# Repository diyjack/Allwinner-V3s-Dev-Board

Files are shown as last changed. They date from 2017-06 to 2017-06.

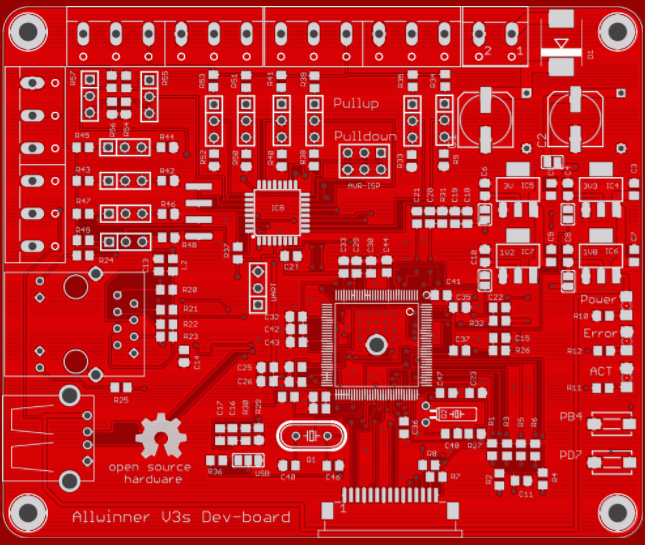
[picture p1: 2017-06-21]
Hardware/Bilder-Platine/top.png

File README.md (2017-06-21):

# Allwinner-V3s-Dev-Board
Entwicklungsplatine für den nicht sehr bekannten V3s Soc von Allwinner. <br>In dieser Version wurde speziell auf die Multimedia Interfaces des V3s verzichtet um das Entwicklungsboard so einfach wie möglich zu halten.<br> Das Entwicklungsboard verfügt über eine 100mbit Ethernet Buchse,
einen USB Host, ein MIPI Kamera Interface(welches kompatibel zur Raspberry Pi Kamera ist), desweiteren kann über eine micro SD-Karte gebootet werden.<br>
Das Entwicklungsboard verfügt über 12 Eingänge / Ausgänge die auf einer Wago-Klemme aufgelegt sind.<br>Das Entwicklungsboard kann mit bis zu 35V DC betrieben werden.<br> Dieses Entwicklungsboard wurde für die Verwendung im industriellen Bereich entwickelt.
Der CO-Prozessor (ATmega328) überwacht die Eingänge und kann ggf. auch geringe Lasten schalten. 

Die Gerber Dateien und der Schaltplan wurden unter der Open Source Hardware Lizenz veröffentlicht und dürfen für den nicht kommerziellen Zweck gerne weiter verwendet werden.

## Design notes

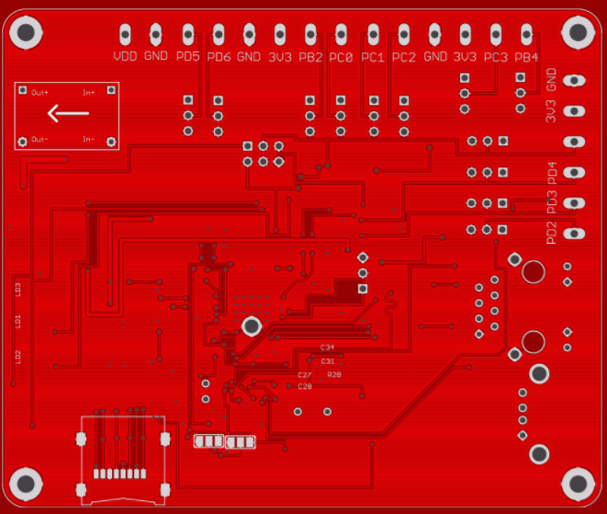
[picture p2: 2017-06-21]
Hardware/Bilder-Platine/Bottom.png

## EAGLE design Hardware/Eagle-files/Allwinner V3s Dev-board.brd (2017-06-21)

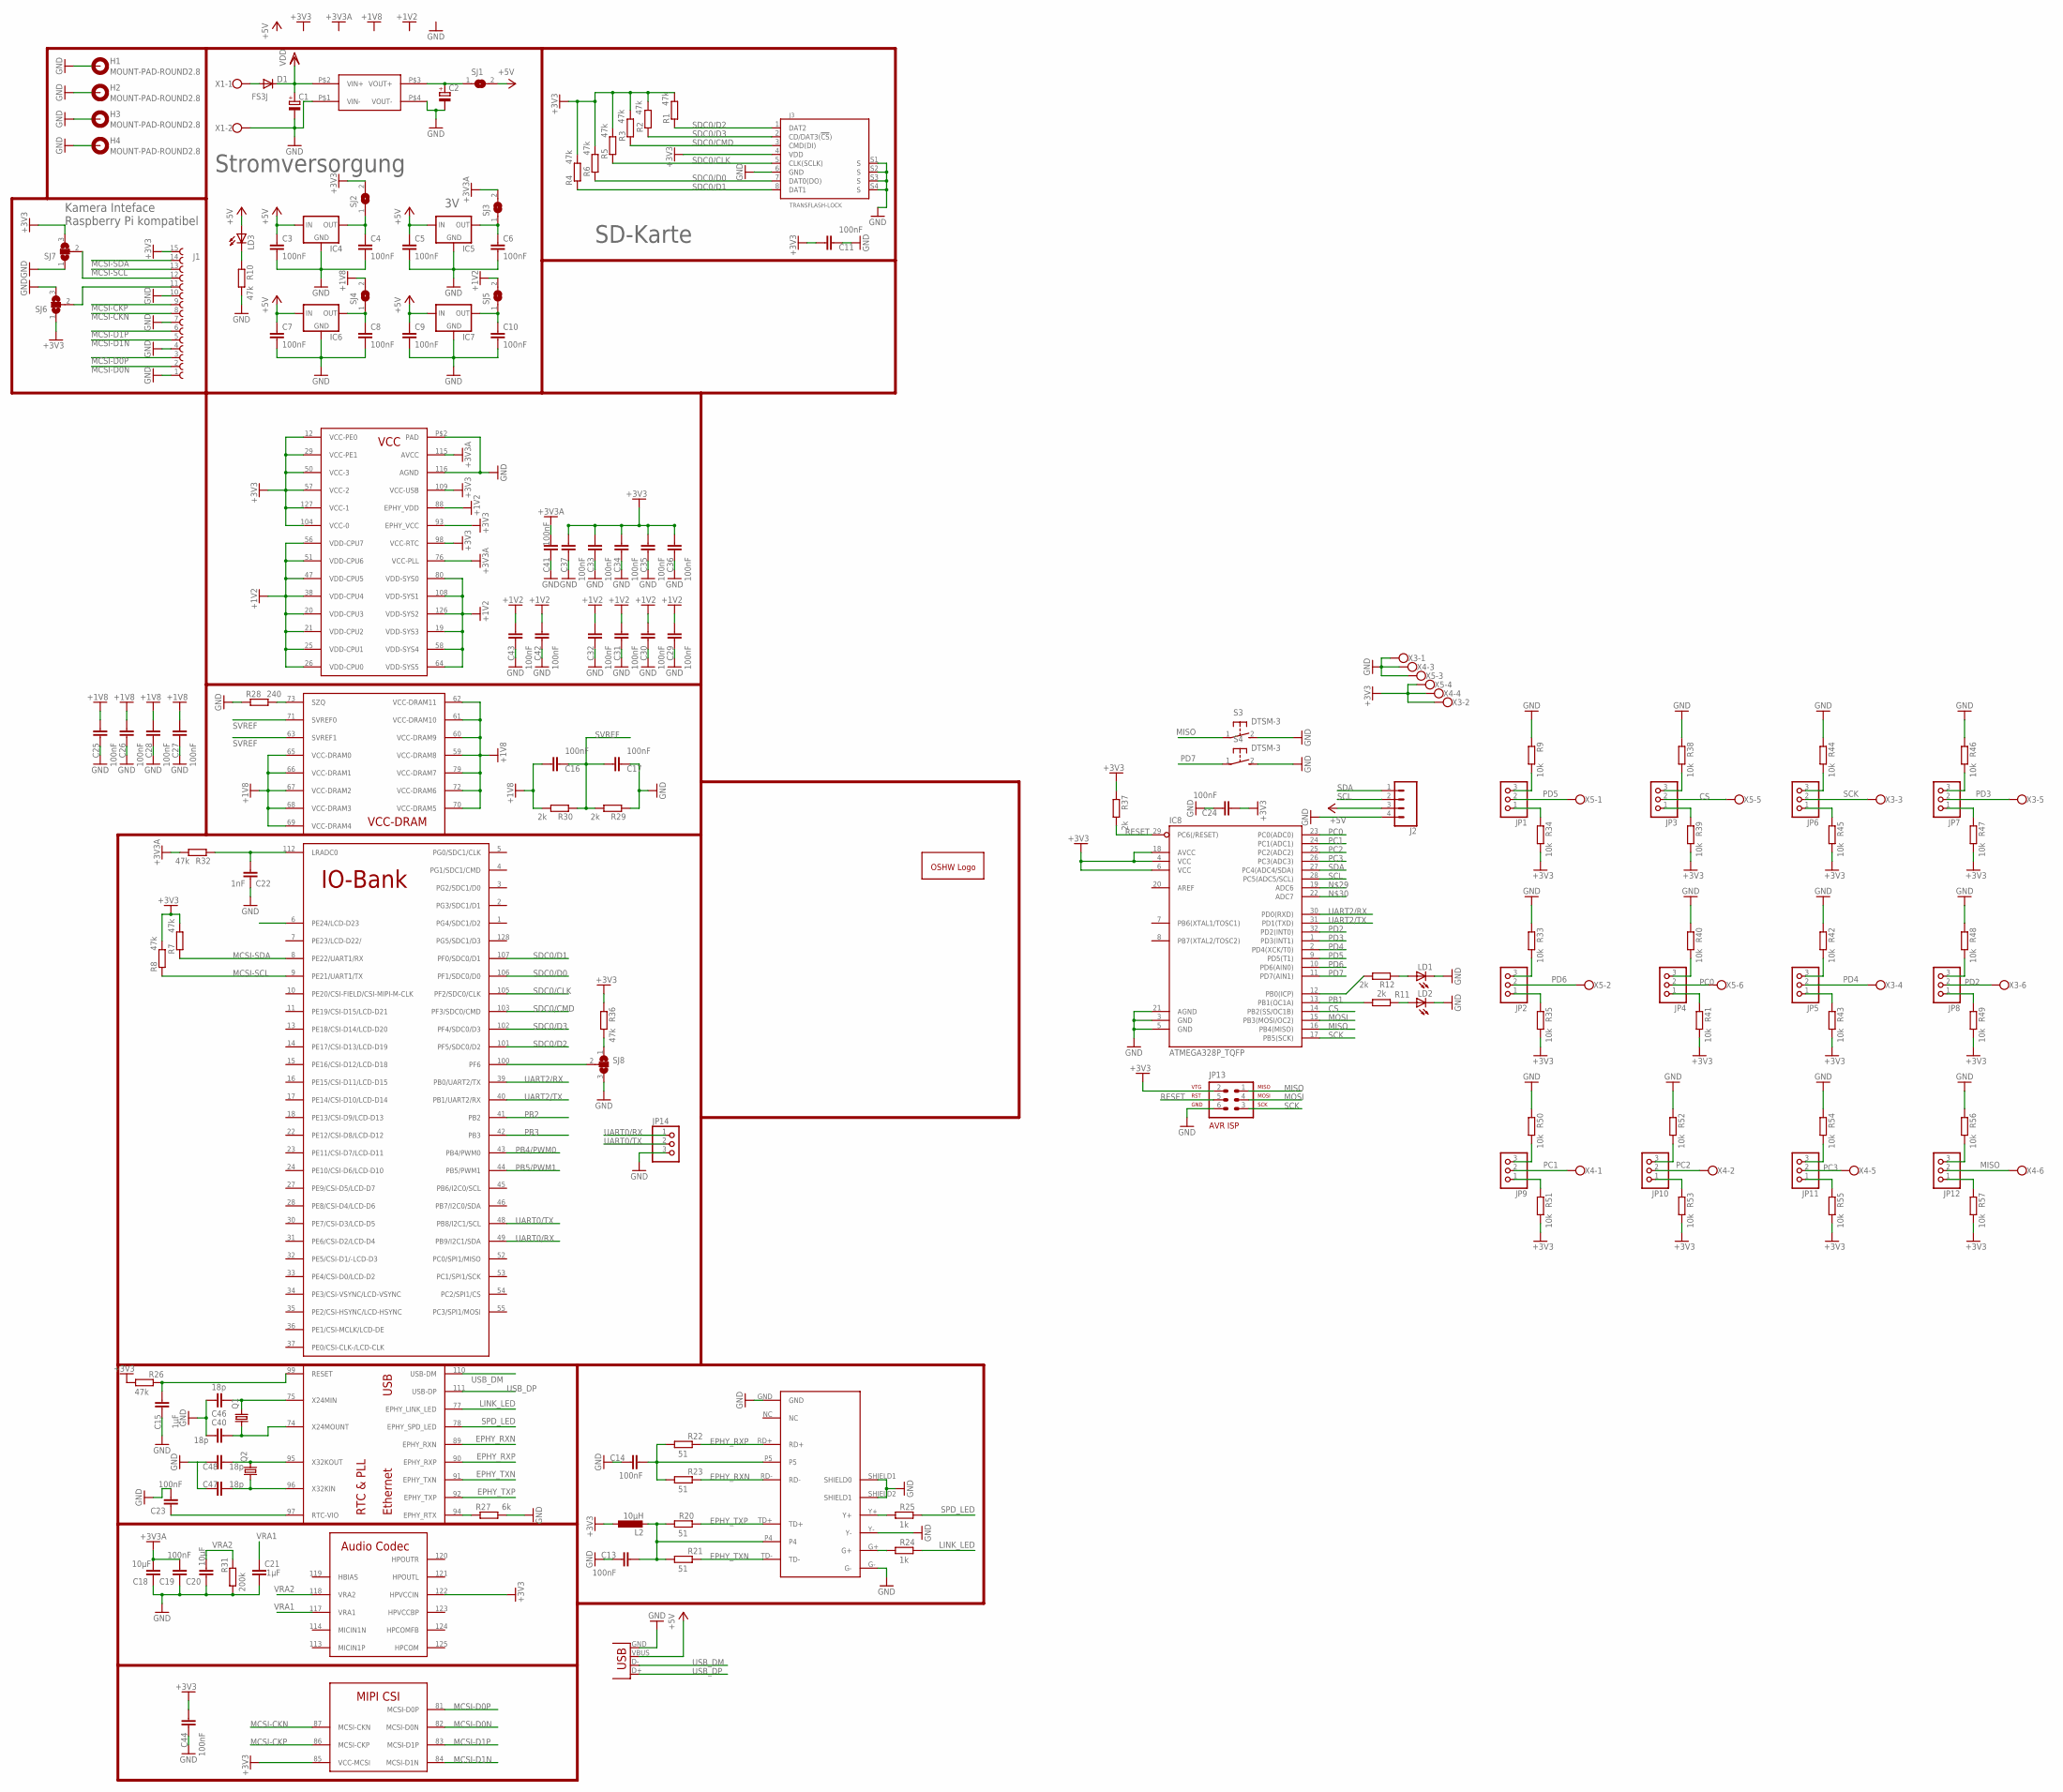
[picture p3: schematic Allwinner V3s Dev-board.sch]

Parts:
C1, C2: CPOL-EU153CLV-0807; 153CLV-0807
C3, C4, C5, C6, C7, C8, C9, C10, C11, C13, C14, C16, C17, C19, C23, C24, C25, C26, C27, C28, C29, C30, C31, C32, C33, C34, C35, C36, C37, C41, C42, C43, C44: 100nF; C0805
C15, C21: 1µF; C0805
C18, C20: 10µF; C0805
C22: 1nF; C0805
C40, C46, C47, C48: 18p; C0805
D1: FS3J; SMC
GOLD_ORB_SM2: OSHWLOGOLOGO8MM; OSHW_8MM
H1, H2, H3, H4: MOUNT-PAD-ROUND2.8; 2,8-PAD
IC1: V3S; QFP-128
IC4, IC5, IC6, IC7: LM1117; SOT223
IC8: ATMEGA328P_TQFP; TQFP32-08
J1: 68611514122
J2: CONN_04SMD_LONG; 1X04_SMD_LONG
J3: TRANSFLASH-LOCK; TRANSFLASH-LOCK-SOCK
JP1, JP2, JP3, JP4, JP5, JP6, JP7, JP8, JP9, JP10, JP11, JP12, JP14: PINHD-1X3; 1X03
JP13: AVR-ISP-6
L2: 10µH; L0805
LD1, LD2, LD3: LEDSMT1206; 1206
M1: MP1584-MINI; MINI-DC-BRICK
Q1: CRYSTALHC49S; HC49/S
Q2: CRYSTALTC26H; TC26H
R1, R2, R3, R4, R5, R6, R7, R8, R10, R26, R32, R36: 47k; R0805
R9, R33, R34, R35, R38, R39, R40, R41, R42, R43, R44, R45, R46, R47, R48, R49, R50, R51, R52, R53, R54, R55, R56, R57: 10k; R0805
R11, R12, R29, R30, R37: 2k; R0805
R20, R21, R22, R23: 51; R0805
R24, R25: 1k; R0805
R27: 6k; R0805
R28: 240; R0805
R31: 200k; R0805
S3, S4: DTSM-3
SJ1, SJ2, SJ3, SJ4, SJ5: SJ
SJ6, SJ7, SJ8: SJ2W; SJ_2
U$3: HR911105A; RJ45
X1: W237-102
X2: USB-A-H
X3, X4, X5: W237-6

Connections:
+1V2: C29.1, C30.1, C31.1, C32.1, C42.1, C43.1, IC1.19 (VDD-SYS3), IC1.20 (VDD-CPU3), IC1.21 (VDD-CPU2), IC1.25 (VDD-CPU1), IC1.26 (VDD-CPU0), IC1.38 (VDD-CPU4), IC1.47 (VDD-CPU5), IC1.51 (VDD-CPU6), IC1.56 (VDD-CPU7), IC1.58 (VDD-SYS4), IC1.64 (VDD-SYS5), IC1.80 (VDD-SYS0), IC1.88 (EPHY_VDD), IC1.108 (VDD-SYS1), IC1.126 (VDD-SYS2), SJ5.2
+1V8: C16.1, C25.1, C26.1, C27.1, C28.1, IC1.59 (VCC-DRAM8), IC1.60 (VCC-DRAM9), IC1.61 (VCC-DRAM10), IC1.62 (VCC-DRAM11), IC1.65 (VCC-DRAM0), IC1.66 (VCC-DRAM1), IC1.67 (VCC-DRAM2), IC1.68 (VCC-DRAM3), IC1.69 (VCC-DRAM4), IC1.70 (VCC-DRAM5), IC1.72 (VCC-DRAM6), IC1.79 (VCC-DRAM7), R30.2, SJ4.2
+3V3: C11.1, C24.1, C33.1, C34.1, C35.1, C36.1, C37.1, C44.1, IC1.12 (VCC-PE0), IC1.29 (VCC-PE1), IC1.50 (VCC-3), IC1.57 (VCC-2), IC1.85 (VCC-MCSI), IC1.93 (EPHY_VCC), IC1.98 (VCC-RTC), IC1.104 (VCC-0), IC1.109 (VCC-USB), IC1.122 (HPVCCIN), IC1.127 (VCC-1), IC8.4 (VCC), IC8.6 (VCC), IC8.18 (AVCC), J1.15 (1), J3.4 (VDD), JP13.2, L2.1, R1.2, R2.2, R3.2, R4.2, R5.2, R6.2, R7.2, R8.2, R26.2, R34.2, R35.2, R36.1, R37.1, R39.2, R41.2, R43.2, R45.2, R47.2, R49.2, R51.2, R53.2, R55.2, R57.2, SJ2.2, SJ6.1, SJ7.3, X3.2, X4.4, X5.4
+3V3A: C18.1, C19.1, C41.1, IC1.76 (VCC-PLL), IC1.115 (AVCC), R32.2, SJ3.2
+5V: C3.1, C5.1, C7.1, C9.1, IC4.3 (IN), IC5.3 (IN), IC6.3 (IN), IC7.3 (IN), J2.3, LD3.A, SJ1.2, X2.VBUS
CS: IC8.14 (PB2(SS/OC1B)), JP3.2, X5.5
EPHY_RXN: IC1.89 (EPHY_RXN), R23.1, U$3.RD-
EPHY_RXP: IC1.90 (EPHY_RXP), R22.1, U$3.RD+
EPHY_TXN: IC1.91 (EPHY_TXN), R21.1, U$3.TD-
EPHY_TXP: IC1.92 (EPHY_TXP), R20.1, U$3.TD+
GND: C1.-, C2.-, C3.2, C4.2, C5.2, C6.2, C7.2, C8.2, C9.2, C10.2, C11.2, C13.2, C14.2, C15.2, C17.2, C18.2, C19.2, C20.2, C21.2, C22.1, C23.1, C24.2, C25.2, C26.2, C27.2, C28.2, C29.2, C30.2, C31.2, C32.2, C33.2, C34.2, C35.2, C36.2, C37.2, C40.1, C41.2, C42.2, C43.2, C44.2, C46.1, C47.1, C48.1, H1.B2,8, H2.B2,8, H3.B2,8, H4.B2,8, IC1.116 (AGND), IC1.P$2 (PAD), IC4.1 (GND), IC5.1 (GND), IC6.1 (GND), IC7.1 (GND), IC8.3 (GND), IC8.5 (GND), IC8.21 (AGND), J1.1 (15), J1.4 (12), J1.7 (9), J1.10 (6), J2.4, J3.6 (GND), J3.S1 (S), J3.S2 (S), J3.S3 (S), J3.S4 (S), JP13.6, JP14.3, LD1.C, LD2.C, M1.P$1 (VIN-), M1.P$4 (VOUT-), R9.1, R10.2, R27.2, R28.1, R29.1, R31.2, R33.1, R38.1, R40.1, R42.1, R44.1, R46.1, R48.1, R50.1, R52.1, R54.1, R56.1, S3.2, S4.2, SJ6.3, SJ7.1, SJ8.3, U$3.G-, U$3.GND, U$3.SHIELD1 (SHIELD0), U$3.SHIELD2 (SHIELD1), U$3.Y-, X1.2, X2.GND, X3.1, X4.3, X5.3
LINK_LED: IC1.77 (EPHY_LINK_LED), R24.1
MCSI-CKN: IC1.87 (MCSI-CKN), J1.8
MCSI-CKP: IC1.86 (MCSI-CKP), J1.9 (7)
MCSI-D0N: IC1.82 (MCSI-D0N), J1.2 (14)
MCSI-D0P: IC1.81 (MCSI-D0P), J1.3 (13)
MCSI-D1N: IC1.84 (MCSI-D1N), J1.5 (11)
MCSI-D1P: IC1.83 (MCSI-D1P), J1.6 (10)
MCSI-SCL: IC1.9 (PE21/UART1/TX), J1.13 (3), R8.1
MCSI-SDA: IC1.8 (PE22/UART1/RX), J1.14 (2), R7.1
MISO: IC8.16 (PB4(MISO)), JP12.2, JP13.1, S3.1, X4.6
MOSI: IC8.15 (PB3(MOSI/OC2)), JP13.4
unnamed: D1.A, X1.1
unnamed: JP2.3, R33.2
unnamed: JP1.3, R9.2
unnamed: C15.1, IC1.99 (RESET), R26.1
unnamed: LD1.A, R12.1
unnamed: LD3.C, R10.1
unnamed: JP1.1, R34.1
unnamed: J1.11 (5), SJ6.2
unnamed: J1.12 (4), SJ7.2
unnamed: IC8.12 (PB0(ICP)), R12.2
unnamed: JP2.1, R35.1
unnamed: JP3.3, R38.2
unnamed: JP3.1, R39.1
unnamed: JP4.3, R40.2
unnamed: C2.+, M1.P$3 (VOUT+), SJ1.1
unnamed: JP4.1, R41.1
unnamed: IC1.94 (EPHY_RTX), R27.1
unnamed: R24.2, U$3.G+
unnamed: IC1.73 (SZQ), R28.2
unnamed: R25.2, U$3.Y+
unnamed: C13.1, L2.2, R20.2, R21.2, U$3.P4
unnamed: C14.1, R22.2, R23.2, U$3.P5
unnamed: C22.2, IC1.112 (LRADC0), R32.1
unnamed: C23.2, IC1.97 (RTC-VIO)
unnamed: IC1.100 (PF6), SJ8.2
unnamed: R36.2, SJ8.1
unnamed: JP5.3, R42.2
unnamed: JP5.1, R43.1
unnamed: JP6.3, R44.2
unnamed: JP6.1, R45.1
unnamed: JP7.3, R46.2
unnamed: JP7.1, R47.1
unnamed: JP8.3, R48.2
unnamed: JP8.1, R49.1
unnamed: JP9.3, R50.2
unnamed: JP9.1, R51.1
unnamed: JP10.3, R52.2
unnamed: JP10.1, R53.1
unnamed: C4.1, IC4.2 (OUT), SJ2.1
unnamed: C6.1, IC5.2 (OUT), SJ3.1
unnamed: C8.1, IC6.2 (OUT), SJ4.1
unnamed: C10.1, IC7.2 (OUT), SJ5.1
unnamed: C40.2, IC1.74 (X24MOUNT), Q1.1
unnamed: C46.2, IC1.75 (X24MIN), Q1.2
unnamed: C47.2, IC1.96 (X32KIN), Q2.1
unnamed: C48.2, IC1.95 (X32KOUT), Q2.2
unnamed: JP11.3, R54.2
unnamed: JP11.1, R55.1
unnamed: JP12.3, R56.2
unnamed: JP12.1, R57.1
unnamed: LD2.A, R11.1
PB1: IC8.13 (PB1(OC1A)), R11.2
PB2: IC1.41 (PB2)
PB3: IC1.42 (PB3)
PB4/PWM0: IC1.43 (PB4/PWM0)
PB5/PWM1: IC1.44 (PB5/PWM1)
PC0: IC8.23 (PC0(ADC0)), JP4.2, X5.6
PC1: IC8.24 (PC1(ADC1)), JP9.2, X4.1
PC2: IC8.25 (PC2(ADC2)), JP10.2, X4.2
PC3: IC8.26 (PC3(ADC3)), JP11.2, X4.5
PD2: IC8.32 (PD2(INT0)), JP8.2, X3.6
PD3: IC8.1 (PD3(INT1)), JP7.2, X3.5
PD4: IC8.2 (PD4(XCK/T0)), JP5.2, X3.4
PD5: IC8.9 (PD5(T1)), JP1.2, X5.1
PD6: IC8.10 (PD6(AIN0)), JP2.2, X5.2
PD7: IC8.11 (PD7(AIN1)), S4.1
RESET: IC8.29 (PC6(/RESET)), JP13.5, R37.2
SCK: IC8.17 (PB5(SCK)), JP6.2, JP13.3, X3.3
SCL: IC8.28 (PC5(ADC5/SCL)), J2.2
SDA: IC8.27 (PC4(ADC4/SDA)), J2.1
SDC0/CLK: IC1.105 (PF2/SDC0/CLK), J3.5 (CLK(SCLK)), R5.1
SDC0/CMD: IC1.103 (PF3/SDC0/CMD), J3.3 (CMD(DI)), R3.1
SDC0/D0: IC1.106 (PF1/SDC0/D0), J3.7 (DAT0(DO)), R6.1
SDC0/D1: IC1.107 (PF0/SDC0/D1), J3.8 (DAT1), R4.1
SDC0/D2: IC1.101 (PF5/SDC0/D2), J3.1 (DAT2), R1.1
SDC0/D3: IC1.102 (PF4/SDC0/D3), J3.2 (CD/DAT3(!CS!)), R2.1
SPD_LED: IC1.78 (EPHY_SPD_LED), R25.1
SVREF: C16.2, C17.1, IC1.63 (SVREF1), IC1.71 (SVREF0), R29.2, R30.1
UART0/RX: IC1.49 (PB9/I2C1/SDA), JP14.1
UART0/TX: IC1.48 (PB8/I2C1/SCL), JP14.2
UART2/RX: IC1.39 (PB0/UART2/TX), IC8.30 (PD0(RXD))
UART2/TX: IC1.40 (PB1/UART2/RX), IC8.31 (PD1(TXD))
USB_DM: IC1.110 (USB-DM), X2.D-
USB_DP: IC1.111 (USB-DP), X2.D+
VDD: C1.+, D1.C, M1.P$2 (VIN+)
VRA1: C21.1, IC1.117 (VRA1)
VRA2: C20.1, IC1.118 (VRA2), R31.1

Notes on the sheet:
Stromversorgung
Kamera Inteface Raspberry Pi kompatibel
SD-Karte

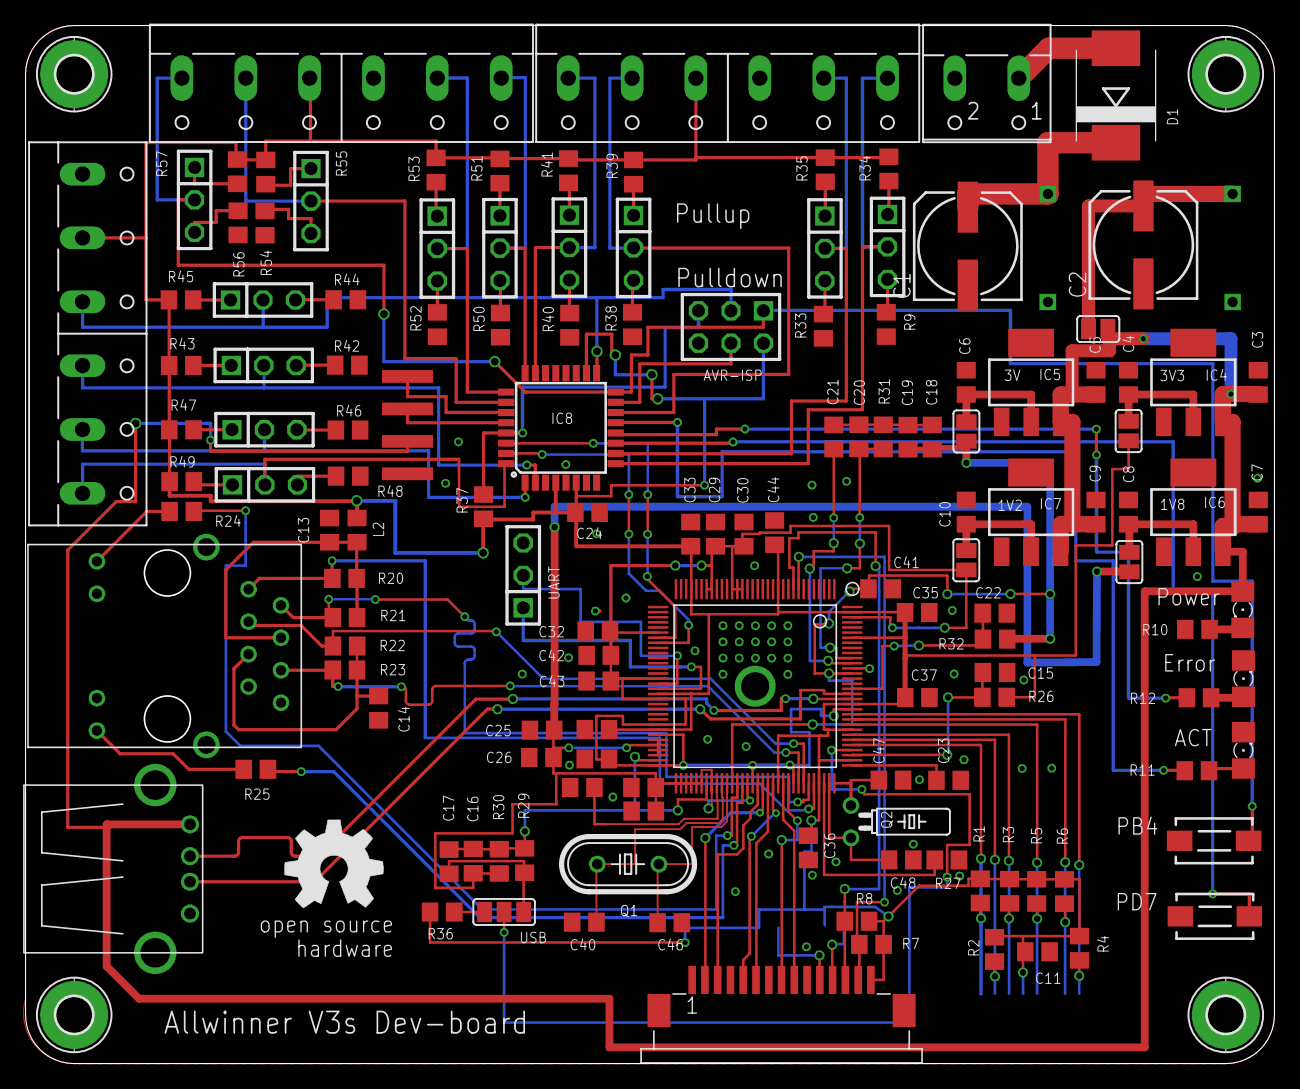
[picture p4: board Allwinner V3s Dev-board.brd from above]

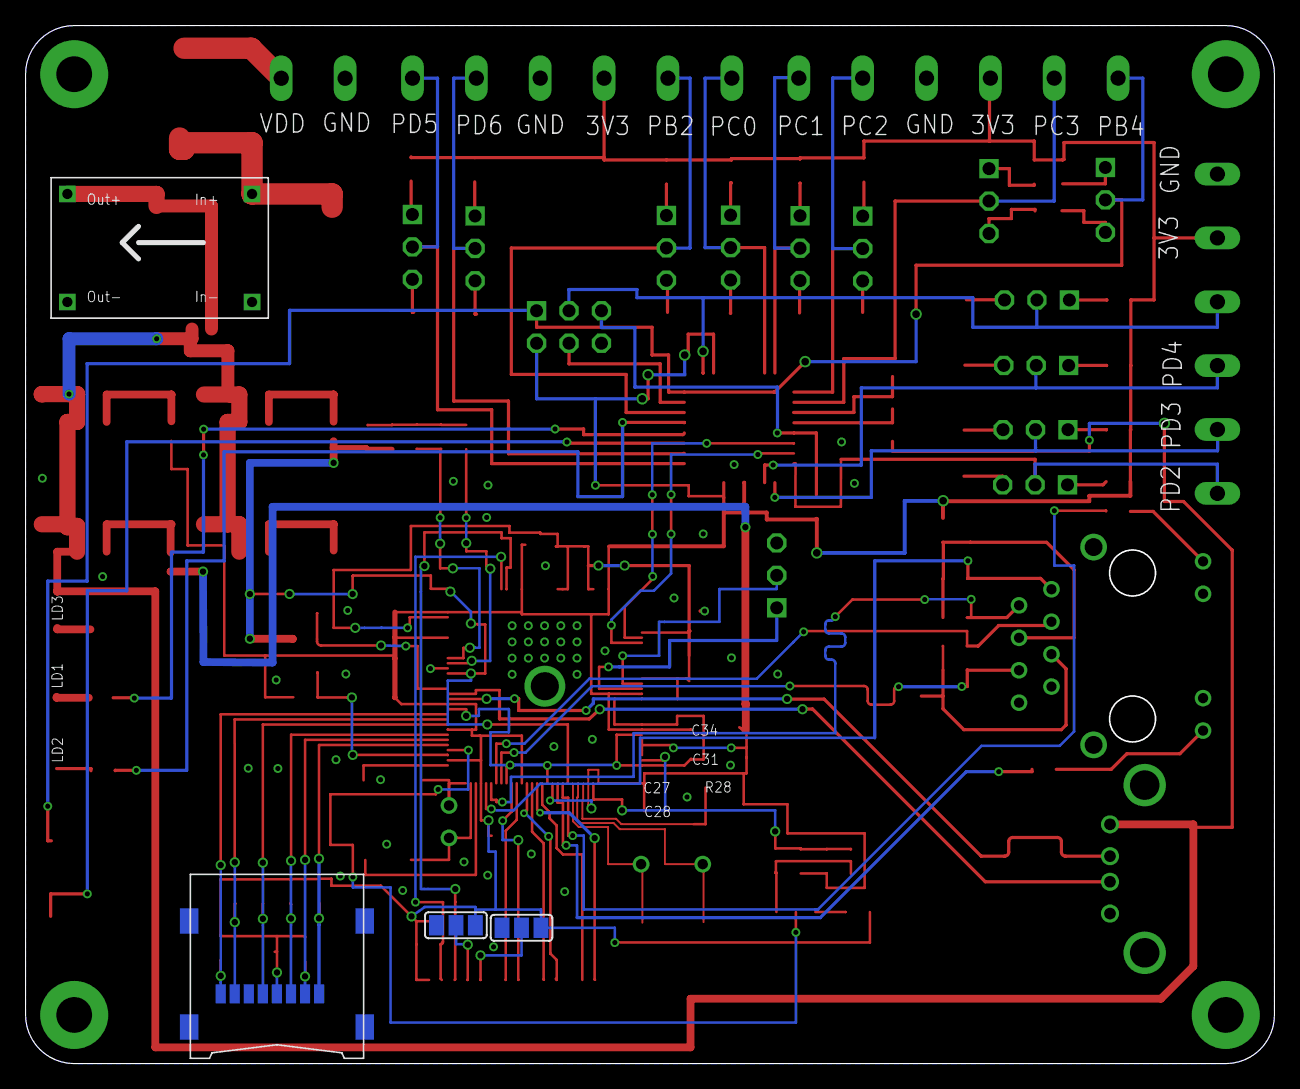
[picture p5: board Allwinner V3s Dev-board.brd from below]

Board: 2 copper layers, 97.8 x 81.3 mm, 146 parts (4 on the bottom side), 105 nets.

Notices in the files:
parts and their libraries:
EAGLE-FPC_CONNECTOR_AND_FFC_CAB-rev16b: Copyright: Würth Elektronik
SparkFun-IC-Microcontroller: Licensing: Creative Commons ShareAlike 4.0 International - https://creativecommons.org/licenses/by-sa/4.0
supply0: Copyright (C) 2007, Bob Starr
